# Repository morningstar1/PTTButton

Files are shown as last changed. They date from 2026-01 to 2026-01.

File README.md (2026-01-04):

# PTTButton
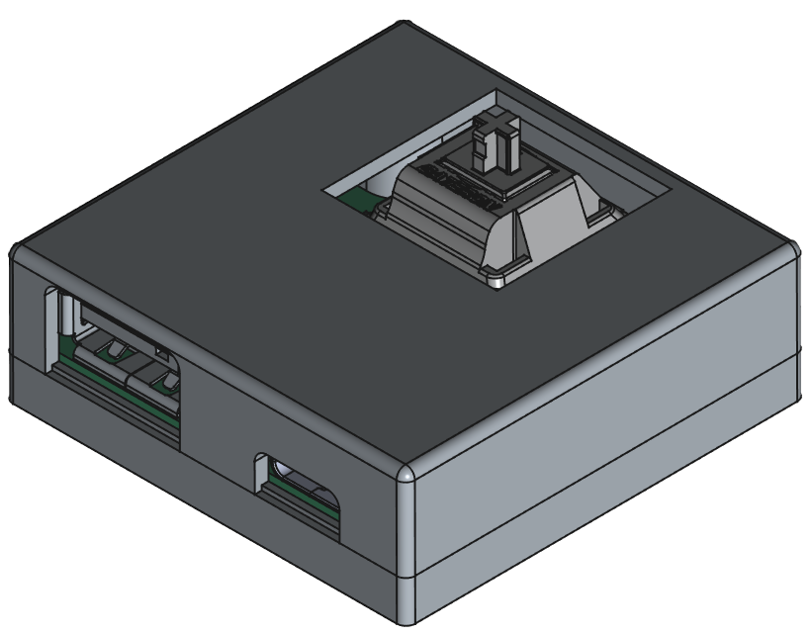
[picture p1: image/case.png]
 
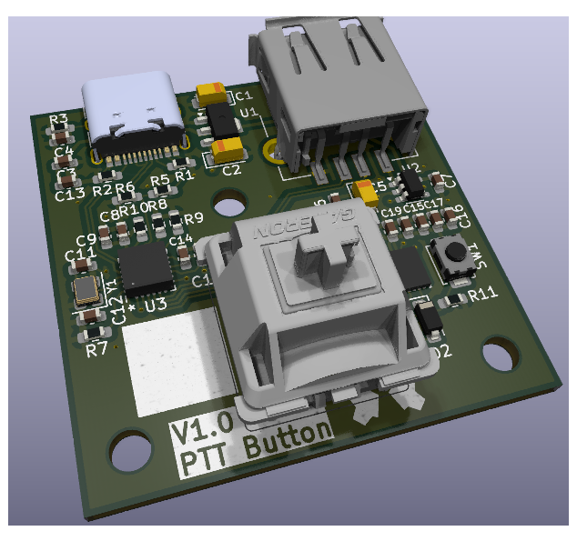
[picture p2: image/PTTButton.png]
PTTButton


## One Button Keyboard

A minimalistic keyboard with just one button.

Inspiered by [fnrow](https://github.com/dinofizz/fnrow-pcb) from Dino Fizzotti.

It uses USB Type C for uplink and has an additional USB Type A downlink port.

Currently uses QMK software from fnrow.

Used Chips:
 * [STM32F042G6U6](docs/stm32f042g6.pdf) Microcontroler
 * [Microchip USB2422](docs/00001726B.pdf) Two Port USB 2.0 Hub
 * [Texas Instruments TPS2051](docs/tps2051.pdf) USB Power Switch

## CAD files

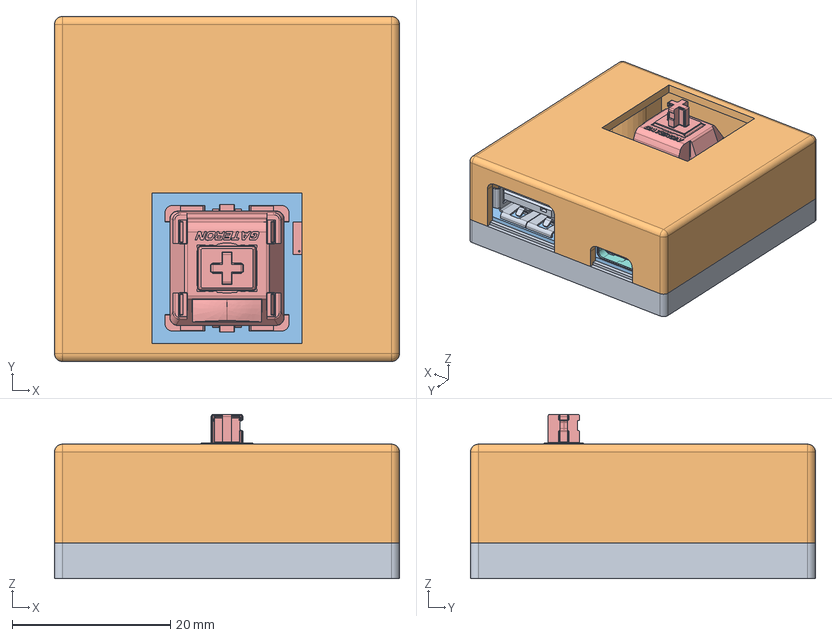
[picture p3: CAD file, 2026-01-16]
Case/PTTButton.FCStd
43.6 x 43.6 x 20.8 mm
Gehäuseunterteil
Gehäuseoberteil
Pcb_26ce
TYPE-C-31-M-12
TYPE-C-31-M-013
TYPE-C-31-M-014
TYPE-C-31-M-015
TYPE-C-31-M-016
TYPE-C-31-M-017
TYPE-C-31-M-018
TYPE-C-31-M-019
TYPE-C-31-M-020
TYPE-C-31-M-021
TYPE-C-31-M-022
TYPE-C-31-M-023
TYPE-C-31-M-024
TYPE-C-31-M-025
TYPE-C-31-M-026
TYPE-C-31-M-027
TYPE-C-31-M-028
TYPE-C-31-M-029
TYPE-C-31-M-030
TYPE-C-31-M-031
TYPE-C-31-M-032
TYPE-C-31-M-033
TYPE-C-31-M-034
TYPE-C-31-M-035
TYPE-C-31-M-036
TYPE-C-31-M-037
TYPE-C-31-M-038
TYPE-C-31-M-039
TYPE-C-31-M-040
TYPE-C-31-M-041
TYPE-C-31-M-042
TYPE-C-31-M-043
TYPE-C-31-M-044
TYPE-C-31-M-045
TYPE-C-31-M-046
TYPE-C-31-M-047
TYPE-C-31-M-048
TYPE-C-31-M-049
TYPE-C-31-M-050
TYPE-C-31-M-051
TYPE-C-31-M-052
TYPE-C-31-M-053
J2_87583-2010BLF_a573260b0f5d
PG151101S11
PG151101S012
PG151101S013
SW2_KS-9 PRO3.0 FWQ_stp_d0f1be47be3c[2]

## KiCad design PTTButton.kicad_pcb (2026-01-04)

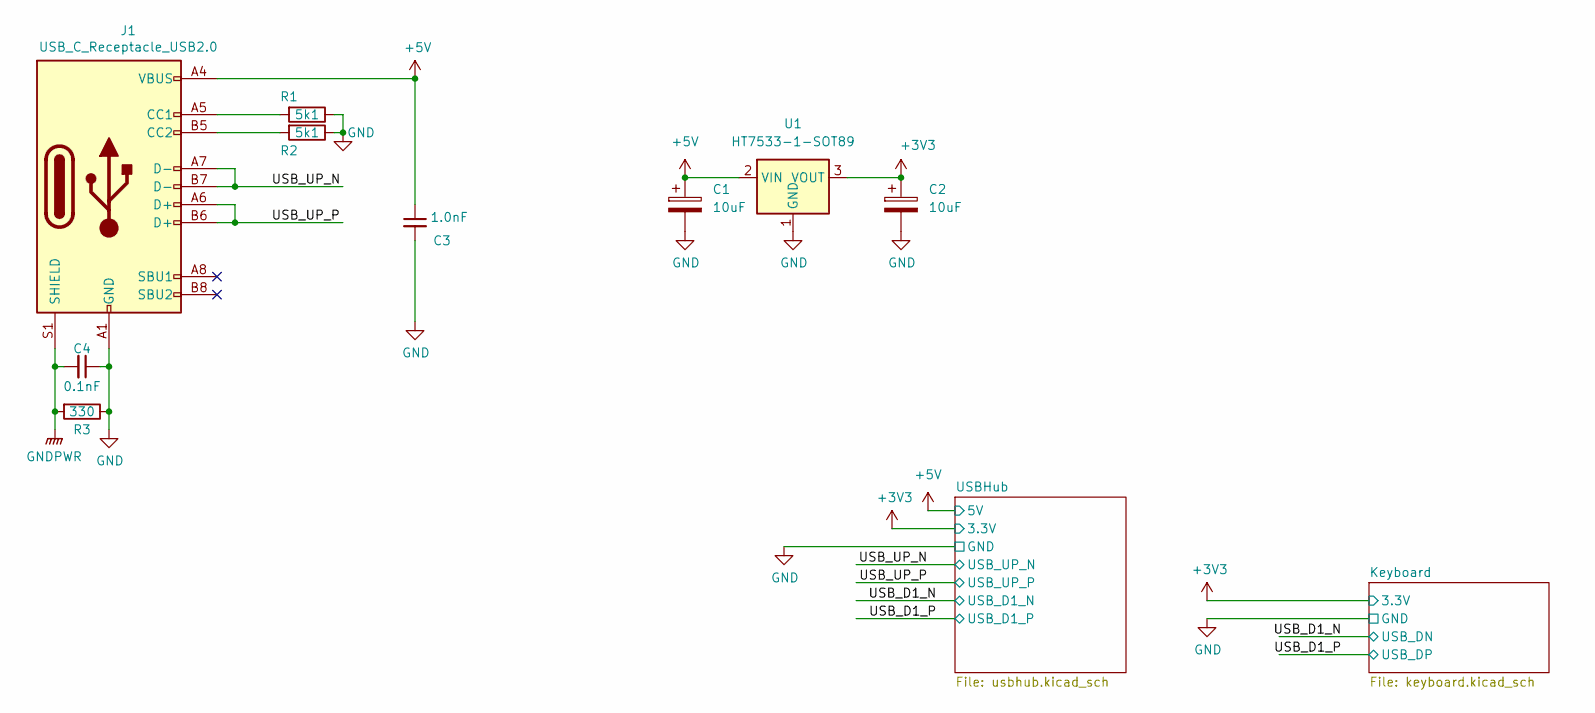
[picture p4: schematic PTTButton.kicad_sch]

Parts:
C1, C2: 10uF; CP_EIA-3216-18_Kemet-A
C3: 1.0nF; C_0603_1608Metric
C4: 0.1nF; C_0603_1608Metric
J1: USB_C_Receptacle_USB2.0; USB_C_Receptacle_HRO_TYPE-C-31-M-12
R1, R2: 5k1; R_0603_1608Metric_Pad0.98x0.95mm_HandSolder
R3: 330; R_0603_1608Metric_Pad0.98x0.95mm_HandSolder
U1: HT7533-1-SOT89; SOT-89-3

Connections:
+3V3: C2.1, U1.3 (VOUT); also elsewhere on the board
+5V: C1.1, C3.1, J1.A4 (VBUS), J1.A9 (VBUS), J1.B4 (VBUS), J1.B9 (VBUS), U1.2 (VIN); also elsewhere on the board
/USB_UP_N: J1.A7 (D-), J1.B7 (D-); also elsewhere on the board
/USB_UP_P: J1.A6 (D+), J1.B6 (D+); also elsewhere on the board
GND: C1.2, C2.2, C3.2, C4.1, J1.A1 (GND), J1.A12 (GND), J1.B1 (GND), J1.B12 (GND), R1.1, R2.1, R3.1, U1.1 (GND); also elsewhere on the board
GNDPWR: C4.2, J1.S1 (SHIELD), R3.2; also elsewhere on the board
unnamed: J1.A5 (CC1), R1.2
unnamed: J1.B5 (CC2), R2.2

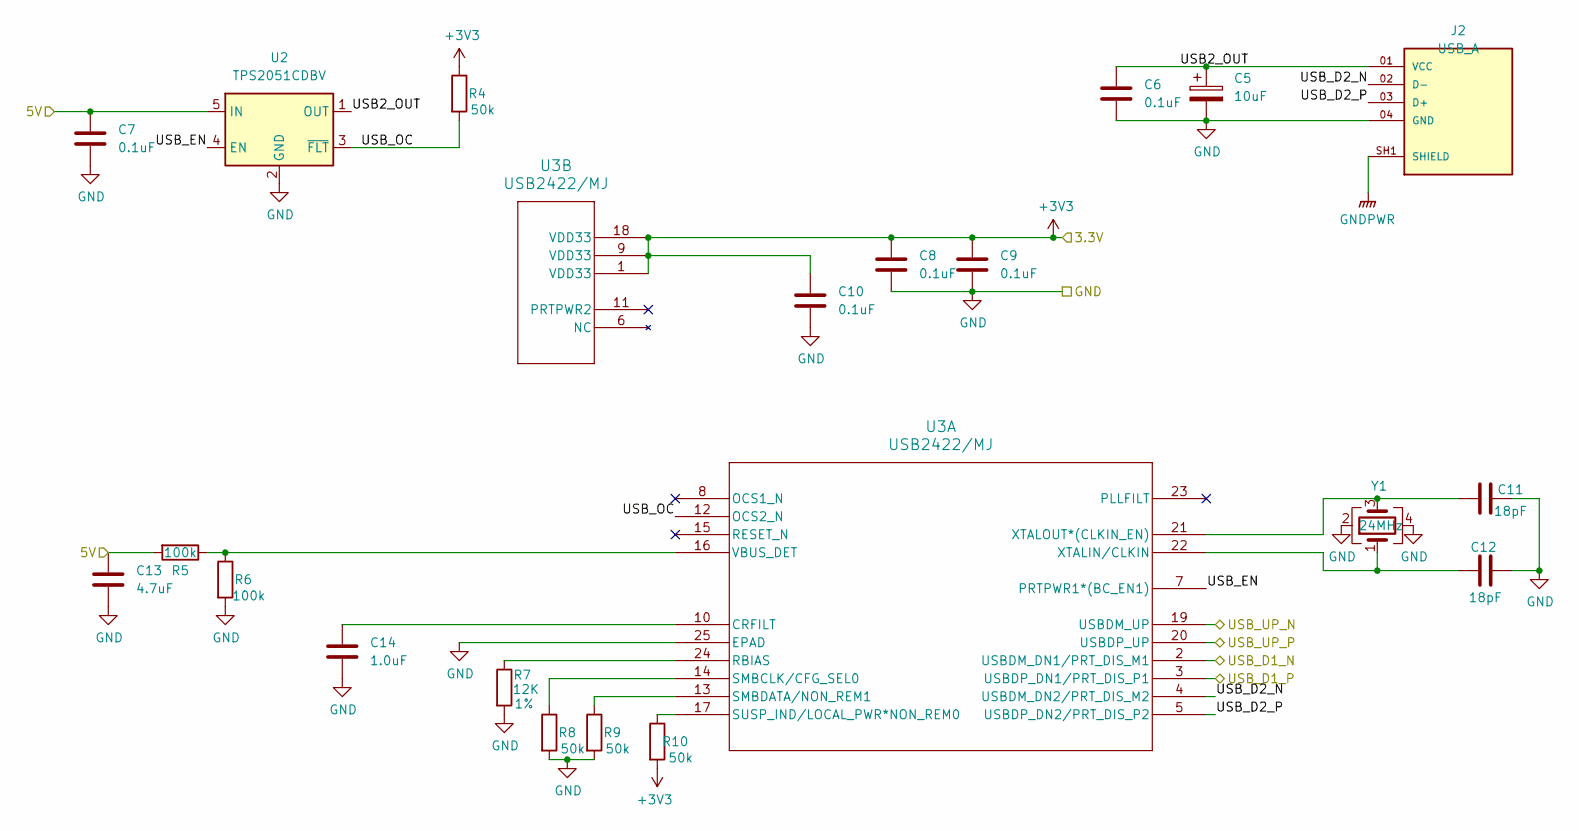
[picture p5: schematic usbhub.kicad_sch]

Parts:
C5: 10uF; CP_EIA-3216-18_Kemet-A
C6, C7, C8, C9, C10: 0.1uF; C_0603_1608Metric
C11, C12: 18pF; C_0603_1608Metric
C13: 4.7uF; C_0603_1608Metric
C14: 1.0uF; C_0603_1608Metric
J2: USB_A; AMPHENOL_87583-2010BLF; PARTREV AD; DigiKey_Part_Number 609-4413-ND
R4, R8, R9, R10: 50k; R_0603_1608Metric_Pad0.98x0.95mm_HandSolder
R5, R6: 100k; R_0603_1608Metric_Pad0.98x0.95mm_HandSolder
R7: 12K; R_0603_1608Metric_Pad0.98x0.95mm_HandSolder
U2: TPS2051CDBV; SOT-23-5
U3: USB2422/MJ; SQFN24_4X4MC_MCH
Y1: 24MHz; Crystal_SMD_2520-4Pin_2.5x2.0mm

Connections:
+3V3: C8.1, C9.1, C10.1, R4.1, R10.2, U3.1 (VDD33), U3.9 (VDD33), U3.18 (VDD33); also elsewhere on the board
+5V: C7.1, C13.1, R5.2, U2.5 (IN); also elsewhere on the board
/USBHub/USB2_OUT: C5.1, C6.1, J2.01 (VCC), U2.1 (OUT)
/USBHub/USB_D2_N: J2.02 (D-), U3.4 (USBDM_DN2/PRT_DIS_M2)
/USBHub/USB_D2_P: J2.03 (D+), U3.5 (USBDP_DN2/PRT_DIS_P2)
/USBHub/USB_EN: U2.4 (EN), U3.7 (PRTPWR1*(BC_EN1))
/USBHub/USB_OC: R4.2, U2.3 (~FLT), U3.12 (OCS2_N)
/USB_D1_N: U3.2 (USBDM_DN1/PRT_DIS_M1); also elsewhere on the board
/USB_D1_P: U3.3 (USBDP_DN1/PRT_DIS_P1); also elsewhere on the board
/USB_UP_N: U3.19 (USBDM_UP); also elsewhere on the board
/USB_UP_P: U3.20 (USBDP_UP); also elsewhere on the board
GND: C5.2, C6.2, C7.2, C8.2, C9.2, C10.2, C11.2, C12.2, C13.2, C14.2, J2.04 (GND), R6.2, R7.2, R8.2, R9.2, U2.2 (GND), U3.25 (EPAD), Y1.2, Y1.4; also elsewhere on the board
GNDPWR: J2.SH1 (SHIELD), J2.SH2 (SHIELD); also elsewhere on the board
unnamed: C14.1, U3.10 (CRFILT)
unnamed: R7.1, U3.24 (RBIAS)
unnamed: R8.1, U3.14 (SMBCLK/CFG_SEL0)
unnamed: R9.1, U3.13 (SMBDATA/NON_REM1)
unnamed: R10.1, U3.17 (SUSP_IND/LOCAL_PWR*NON_REM0)
unnamed: R5.1, R6.1, U3.16 (VBUS_DET)
unnamed: C12.1, U3.22 (XTALIN/CLKIN), Y1.1
unnamed: C11.1, U3.21 (XTALOUT*(CLKIN_EN)), Y1.3

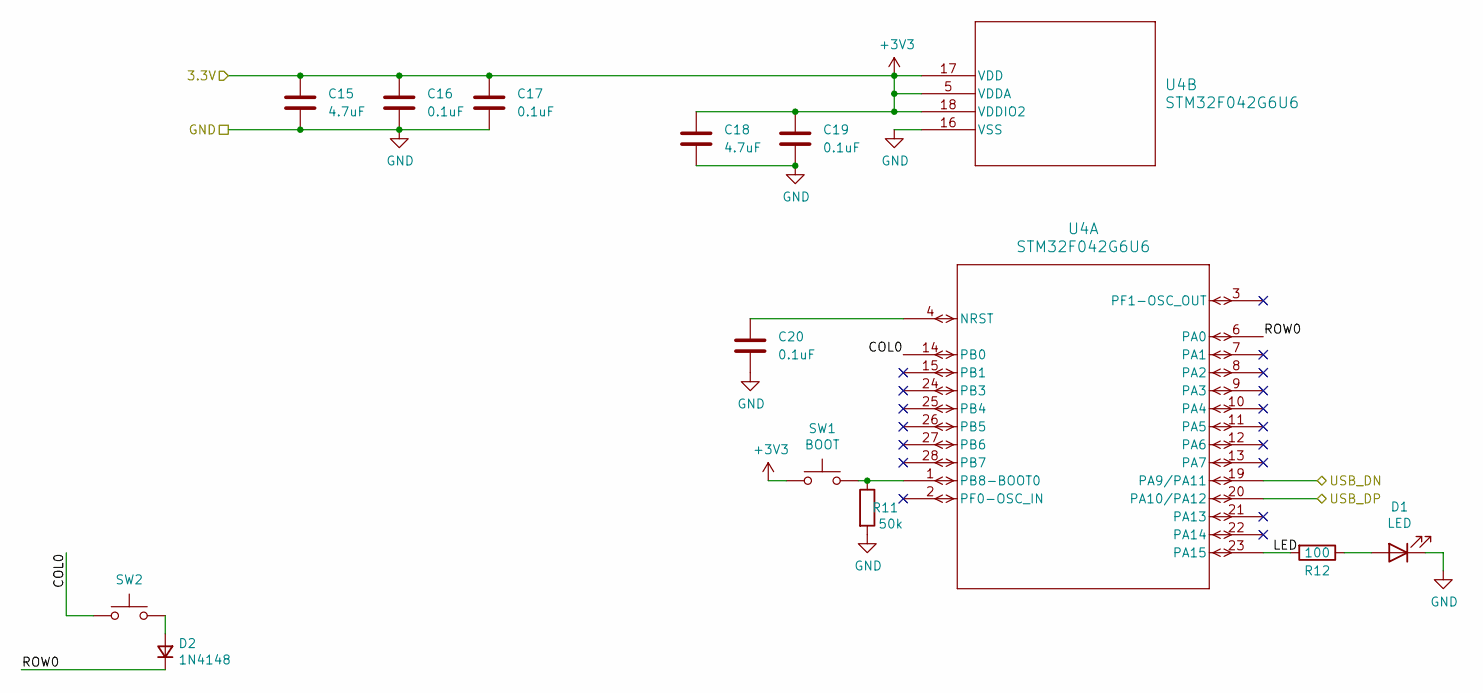
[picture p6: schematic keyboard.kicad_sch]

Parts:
C15, C18: 4.7uF; C_0603_1608Metric
C16, C17, C19, C20: 0.1uF; C_0603_1608Metric
D1: LED; LED_0805_2012Metric_Pad1.15x1.40mm_HandSolder; JLCPCB C2297
D2: 1N4148; D_SOD-123
R11: 50k; R_0603_1608Metric_Pad0.98x0.95mm_HandSolder
R12: 100; R_0603_1608Metric_Pad0.98x0.95mm_HandSolder
SW1: BOOT; SW_SPST_TS-1088-xR020; JLCPCB C720477
SW2: SW_Push; MX100H
U4: STM32F042G6U6; UFQFPN28-4x4mm

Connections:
+3V3: C15.1, C16.1, C17.1, C18.1, C19.1, SW1.1, U4.5 (VDDA), U4.17 (VDD), U4.18 (VDDIO2); also elsewhere on the board
/Keyboard/COL0: SW2.2, U4.14 (PB0)
/Keyboard/LED: R12.2, U4.23 (PA15)
/Keyboard/ROW0: D2.1 (K), U4.6 (PA0)
/USB_D1_N: U4.19 (PA9/PA11); also elsewhere on the board
/USB_D1_P: U4.20 (PA10/PA12); also elsewhere on the board
GND: C15.2, C16.2, C17.2, C18.2, C19.2, C20.2, D1.1 (K), R11.2, U4.16 (VSS); also elsewhere on the board
unnamed: D1.2 (A), R12.1
unnamed: D2.2 (A), SW2.1
unnamed: C20.1, U4.4 (NRST)
unnamed: R11.1, SW1.2, U4.1 (PB8-BOOT0)

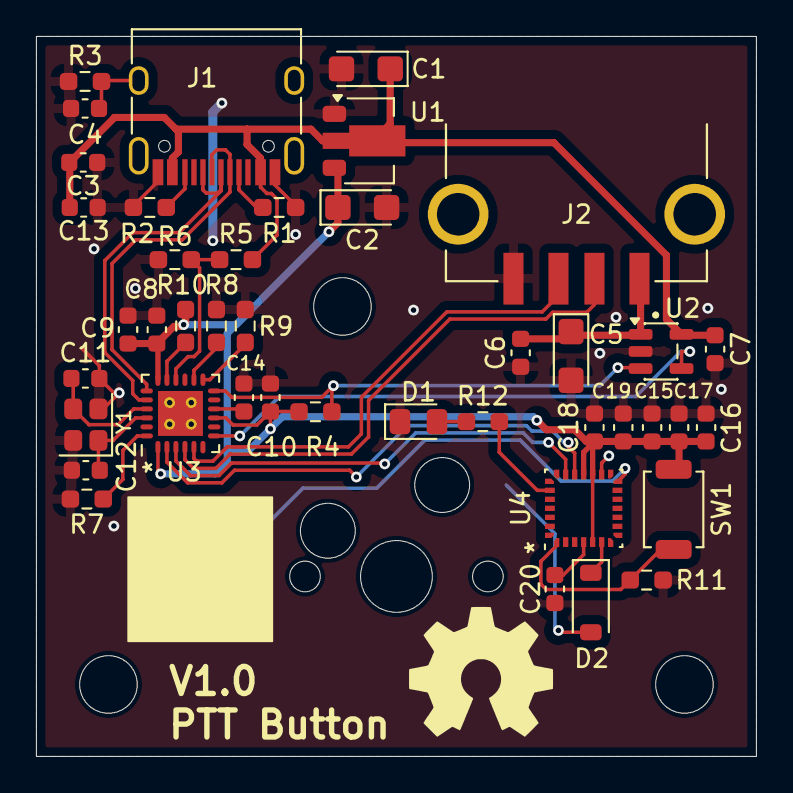
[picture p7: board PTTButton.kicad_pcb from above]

Board: 2 copper layers, 40.0 x 40.0 mm, 43 parts (1 on the bottom side), 30 nets.

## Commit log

2026-01-04 First Release
    [PTTButton.FCStd, PTTButton.kicad_pcb, PTTButton.kicad_sch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]
2026-01-10 Update Case Sizes
    [PTTButton.FCStd]
2026-01-16 enlarge thredded insert hole
    [PTTButton.FCStd]
